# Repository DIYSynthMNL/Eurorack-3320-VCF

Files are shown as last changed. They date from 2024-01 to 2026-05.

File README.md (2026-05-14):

# Eurorack-3320-VCF

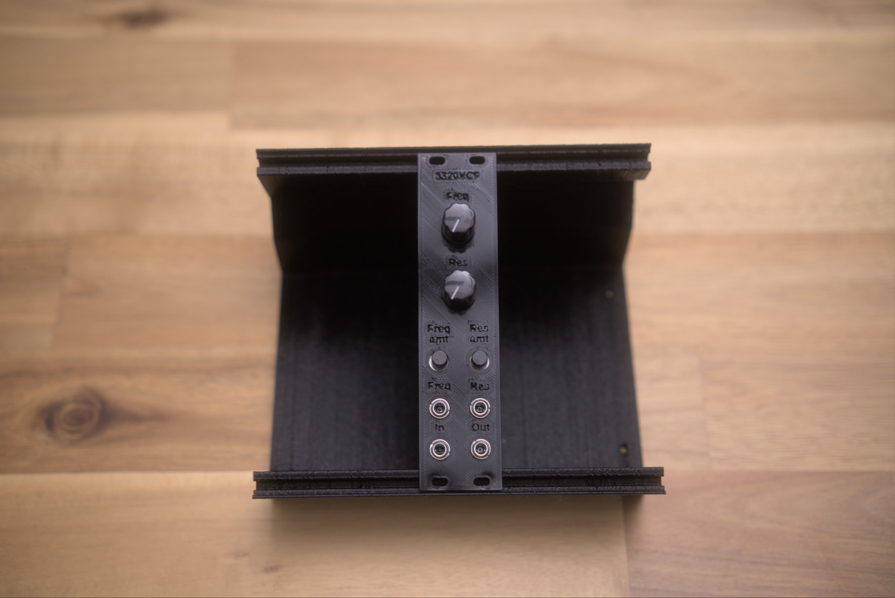
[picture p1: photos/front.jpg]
AS3320 VCF assembled


A Eurorack 4-pole low-pass voltage-controlled filter based on the [AS3320](https://electricdruid.net/product/as3320-vcf/) chip from Electric Druid — a high-performance 4-pole VCF (CEM3372 family). 12-octave cutoff sweep range and voltage-controlled resonance from zero to oscillation.

## Features

- **4-pole (24 dB/oct) low-pass response** using all four AS3320 filter stages
- **12-octave cutoff range** with smooth exponential control
- **Voltage-controlled resonance** — from zero to self-oscillation
- **Cutoff frequency** controlled by a panel pot + CV input with attenuation
- **Resonance** controlled by a panel pot + CV input with attenuation
- **Three calibration trims**:
  - Freq CV gain trim (RV2)
  - Reso CV gain trim (RV5)
  - Output amplitude trim (RV1)
- Eurorack ±12V power via either 16-pin IDC or 3-pin JST connector
- "Sequential Pro One"-style output buffer with AC coupling
- Audio inputs handle 10 Vpp directly (no input AC coupling needed)

## Inputs and outputs

| Jack | Range | Notes |
|---|---|---|
| Sig In | 10 Vpp | Through 100K input buffer, then to filter chain via 91K |
| Freq CV | 10 Vpp | Mixed with front-panel Freq Control via summing amp |
| Res CV | 10 Vpp | Mixed with front-panel Reso Control via summing amp |
| Sig Out | ≤9 Vpp | AC-coupled, gain-2 output buffer with amplitude trim |

## Block diagram

```
Sig In ─► [TL072 input buffer, U1A] ─► [91K] ─► AS3320 IN1
                                                  │
                                                  ▼ Stage 1 (LP)
                                                IN2 ─► Stage 2 (LP) ─► IN3 ─► Stage 3 (LP) ─► IN4 ─► Stage 4 (LP) ─► Out4
                                                                                                                       │
                                                                                                                       ▼
                                                                                                              [2.2 µF AC couple]
                                                                                                                       │
                                                                                                                       ▼
                                                                                                       [TL072 gain-2 + amp trim] ─► Sig Out
                                                                                                                       │
                                                                                                                       └─► [3.3K] ─► AS3320 Vres (resonance feedback)

Freq Control pot ─► [100K] ─┬─► [TL074 summing amp + RV2 gain trim] ─► AS3320 VCFI (pin 12)
Freq CV jack (RV4 atten) ──►┘

Reso Control pot ─► [100K] ─┬─► [TL074 stage 1 + RV5 gain trim] ─► [TL074 stage 2, 100K/150K] ─► [3.3K] ─► AS3320 Ires (pin 9)
Reso CV jack (RV7 atten) ──►┘

Power: Eurorack ±12V ─► local +12V (filtered) and −12V (filtered)
       AS3320 VEE: −12V via REE (R22 = 1.2K) → internal −2.7V regulator
       AS3320 VCC: +12V direct
       Filter stage Rb resistors (R12/R13/R14): 220K to −12V (note: 240K recommended for +12V VCC per datasheet)
       Filter timing caps (C3–C6): 270 pF each (cap1–cap4 pins)
```

## Power

- Eurorack ±12V via **J5** (3-pin JST) or **J6** (16-pin IDC) — populate one
- D1 / D2: reverse-polarity protection
- C9 / C12 (22 µF): bulk rail decoupling
- C10 / C11 (100 nF): op-amp supply decoupling
- **R22 = 1.2 kΩ — AS3320 VEE current limit resistor.** *Required* — the chip has an internal −2.7V regulator and must not see more than ~8 mA on the VEE pin.

REE formula from datasheet: **REE = (|VEE| − 2.7) / 0.008**

| VEE supply | REE |
|---|---|
| −10V | 910 Ω |
| −12V | 1.2 kΩ ← *used here* |
| −15V | 1.5 kΩ |

## Calibration

Three trim pots. Adjust in order, with the module warmed up ~5 minutes.

**RV1 — Output amplitude trim.** Sets final output level. The chip's max output is roughly VCC − 3V (so ~9 Vpp at +12V). Trim until output reaches 10 Vpp at modest input + maximum resonance.

**RV2 — Freq CV gain trim.** Sets the gain of the Freq CV path. Tune to taste — full range of the Freq CV jack should produce a musically-useful filter sweep.

**RV5 — Reso CV gain trim.** Sets the gain of the Reso CV path. At maximum reso CV, filter should reach self-oscillation; at minimum, no resonance.

Procedure:
1. With the module warmed up, set Freq Control to mid, Reso Control to min, no inputs patched.
2. Patch a steady audio signal (sawtooth from a VCO, ~−10 dB) into Sig In and a scope on Sig Out.
3. Adjust RV1 until peak output is ~10 Vpp without clipping.
4. Sweep Freq Control by hand; should hear the filter open and close smoothly.
5. Raise Reso Control — should hear the resonant peak grow, eventually self-oscillating at high values.
6. With a 0–5V LFO patched into Reso CV (jack pot RV7 fully open), adjust RV5 to get the same self-oscillation behavior when CV-driven as you got from the panel pot.
7. With a 0–5V LFO patched into Freq CV (jack pot RV4 fully open), adjust RV2 to get a similar full-range sweep when CV-driven.

## Design references

Local archived copies live in [`references/`](references/) so this repo stays useful if the upstream links die.

- **AS3320 datasheet** — [local copy](references/AS3320-alfatriode-2023.pdf) · [upstream (alfatriode.lv)](https://alfatriode.lv/eng/sc/AS3320.pdf) — definitive reference for the chip
- [Electric Druid AS3320 product page](https://electricdruid.net/product/as3320-vcf/)
- [Electric Druid multimode filter notes](https://electricdruid.net/multimode-filters-part-1-reconfigurable-filters/) — the AS3320 can be wired for LPF / HPF / BPF / APF; this design is LPF only
- Output buffer topology adapted from the Sequential Pro One synth
- [Falstad simulations](falstad/) of input, frequency control, resonance control, and output sub-circuits

## Build status

What's ready for builders today, and what's still on the TODO list:

**Production assets**

- [x] Schematic — Rev 0.1.5 ([PDF](Schematic%20PDFs/3320-VCF_Schematic-Rev-0.1.5.pdf))
- [ ] PCB layout — rev 0.1.0 separated for fab in `kicad/Separate boards/rev0.1.0/`; schematic has advanced to 0.1.5, **re-separation pending**
- [ ] Gerber files for fabrication — none yet
- [ ] BOM — none yet
- [ ] Final front panel (SVG/PDF for fab) — none yet
- [ ] License — none yet

**Prototype assets**

- [x] 3D-printed prototype panel STL — [3320_VCF.stl](3D%20Printed%20Panel/3320_VCF.stl)
- [x] Falstad simulations — [falstad/](falstad/)

**Documentation**

- [x] Photos of the assembled module — see [photos/](photos/)
- [ ] Demo video — none yet
- [ ] Build / assembly instructions — none yet
- [x] Calibration / tuning notes — see "Calibration" section above

Want to help fill a gap (build photos, gerbers, an assembly guide)? Open an issue or PR.

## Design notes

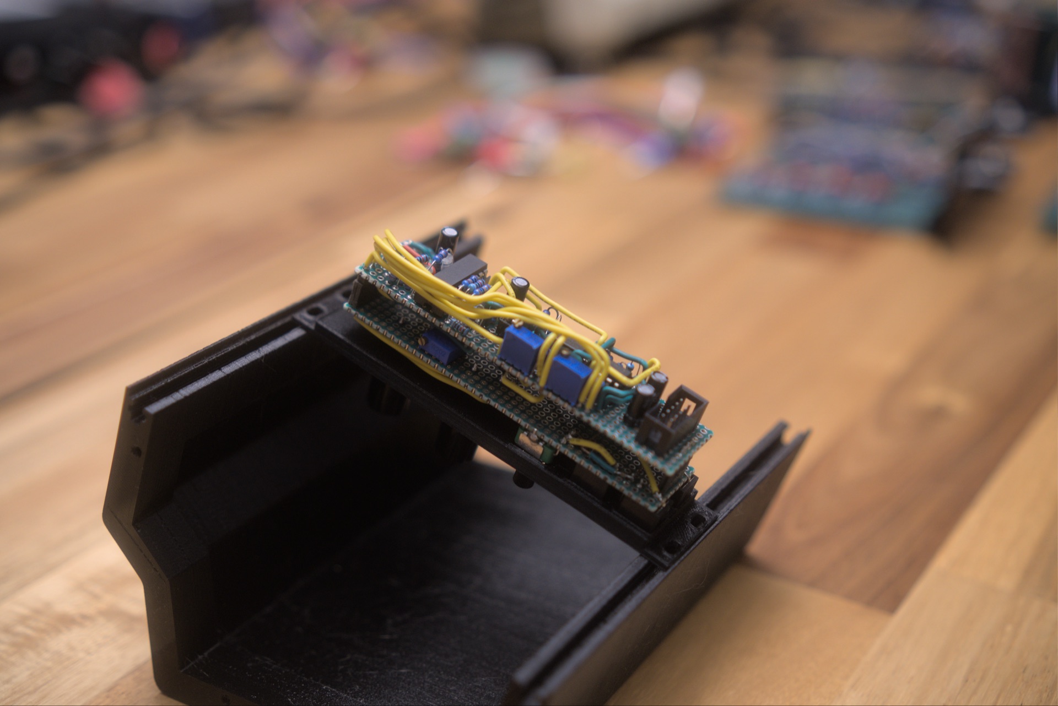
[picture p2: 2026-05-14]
photos/prototype-board-side.jpg

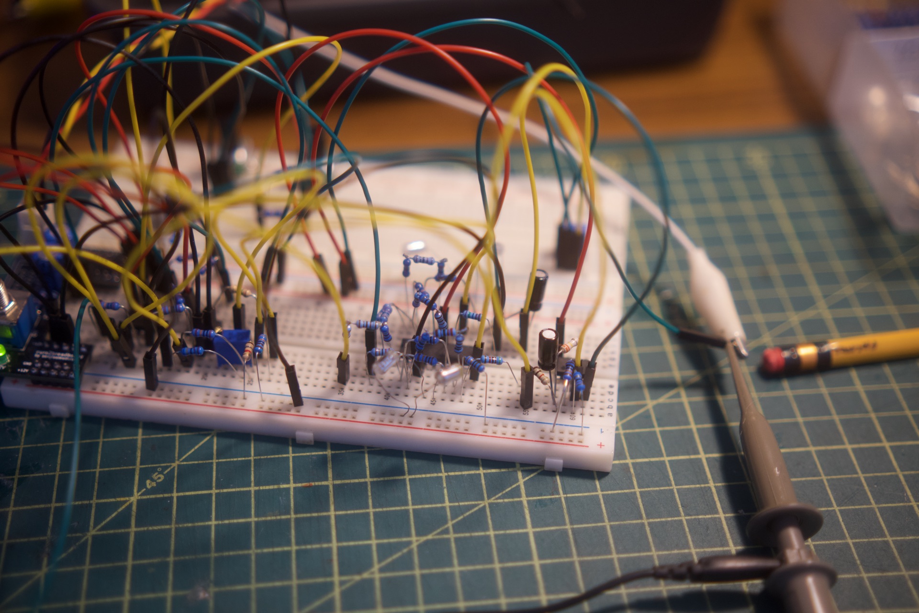
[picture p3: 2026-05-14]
photos/breadboarding/breadboard-2.jpg

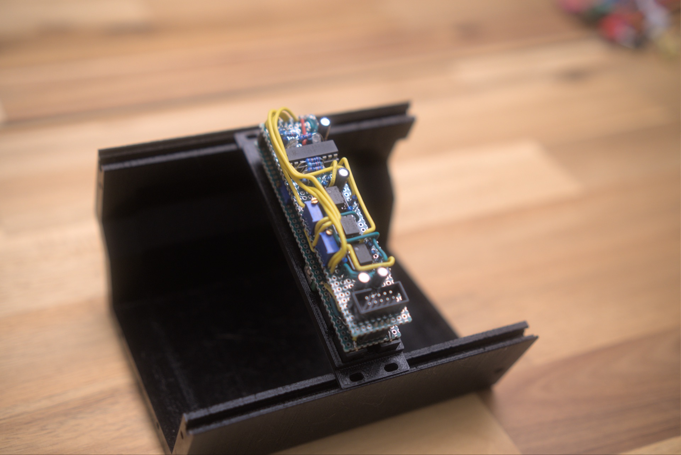
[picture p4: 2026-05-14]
photos/prototype-board.jpg

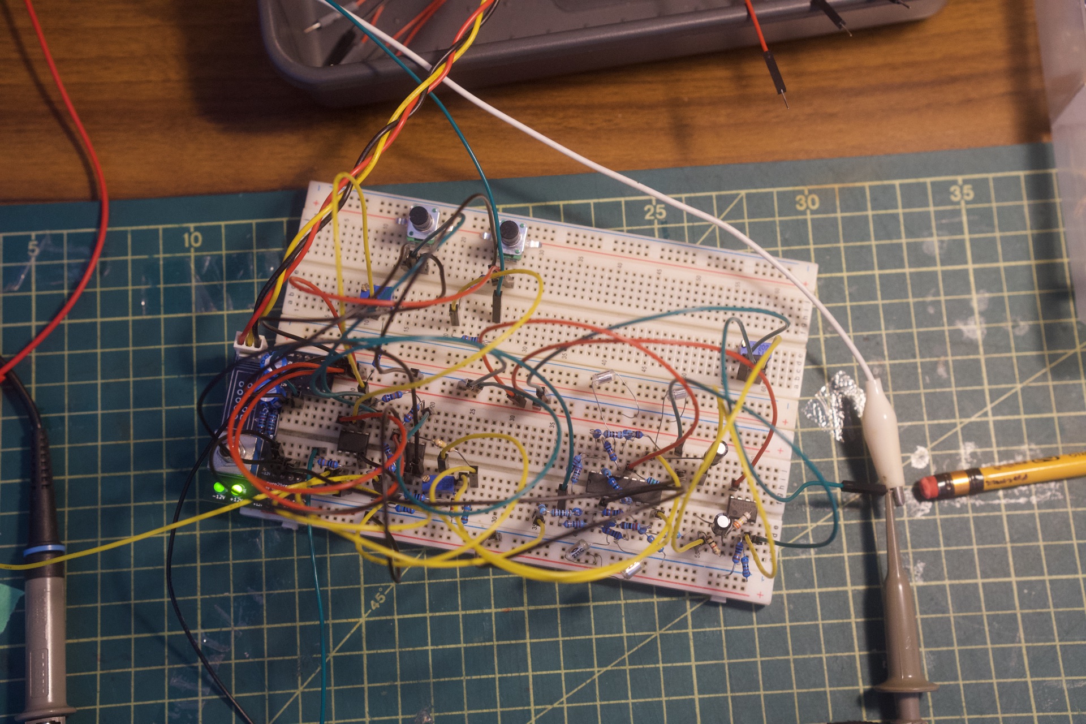
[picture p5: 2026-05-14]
photos/breadboarding/breadboard-1.jpg

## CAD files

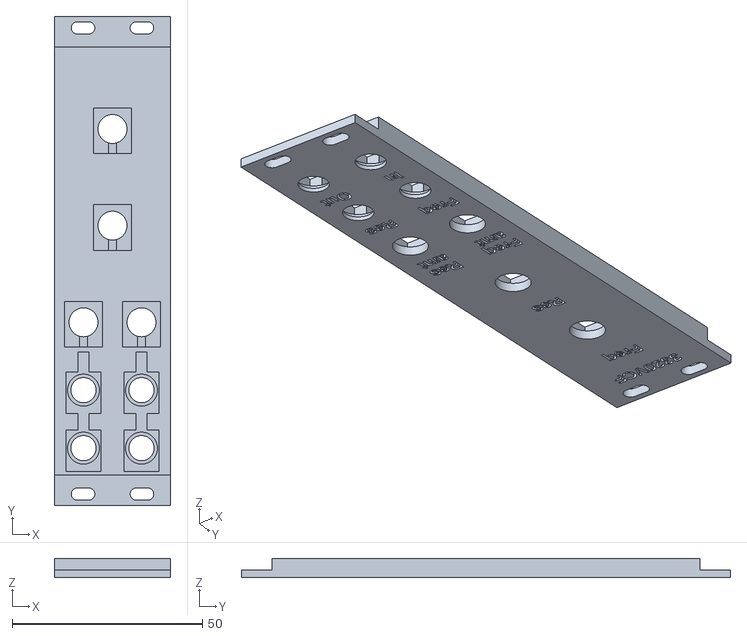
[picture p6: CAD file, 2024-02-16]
3D Printed Panel/3320_VCF.stl
30.5 x 128.5 x 5.00

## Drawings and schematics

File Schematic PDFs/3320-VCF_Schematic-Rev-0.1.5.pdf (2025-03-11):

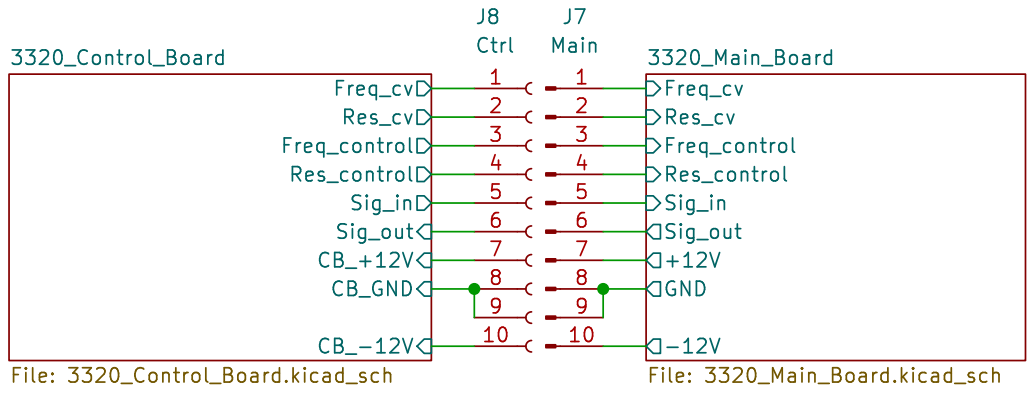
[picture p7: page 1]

File: 3320-VCF.kicad_sch Sheet: / DIYSynthMNL

Id: 1/3 Title: Eurorack 3320 Low Pass VCF

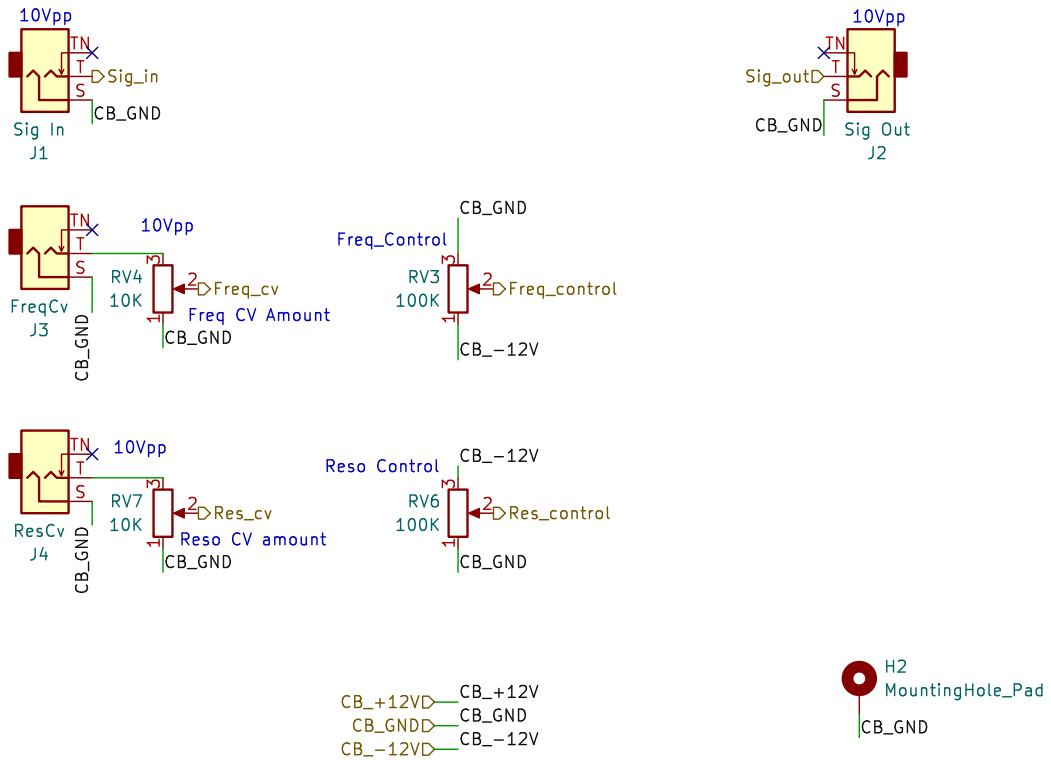
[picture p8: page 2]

DIYSynthMNL
File: 3320_Control_Board.kicad_sch Sheet: /3320_Control_Board/
Id: 2/3 Title: Eurorack 3320 Low Pass VCF

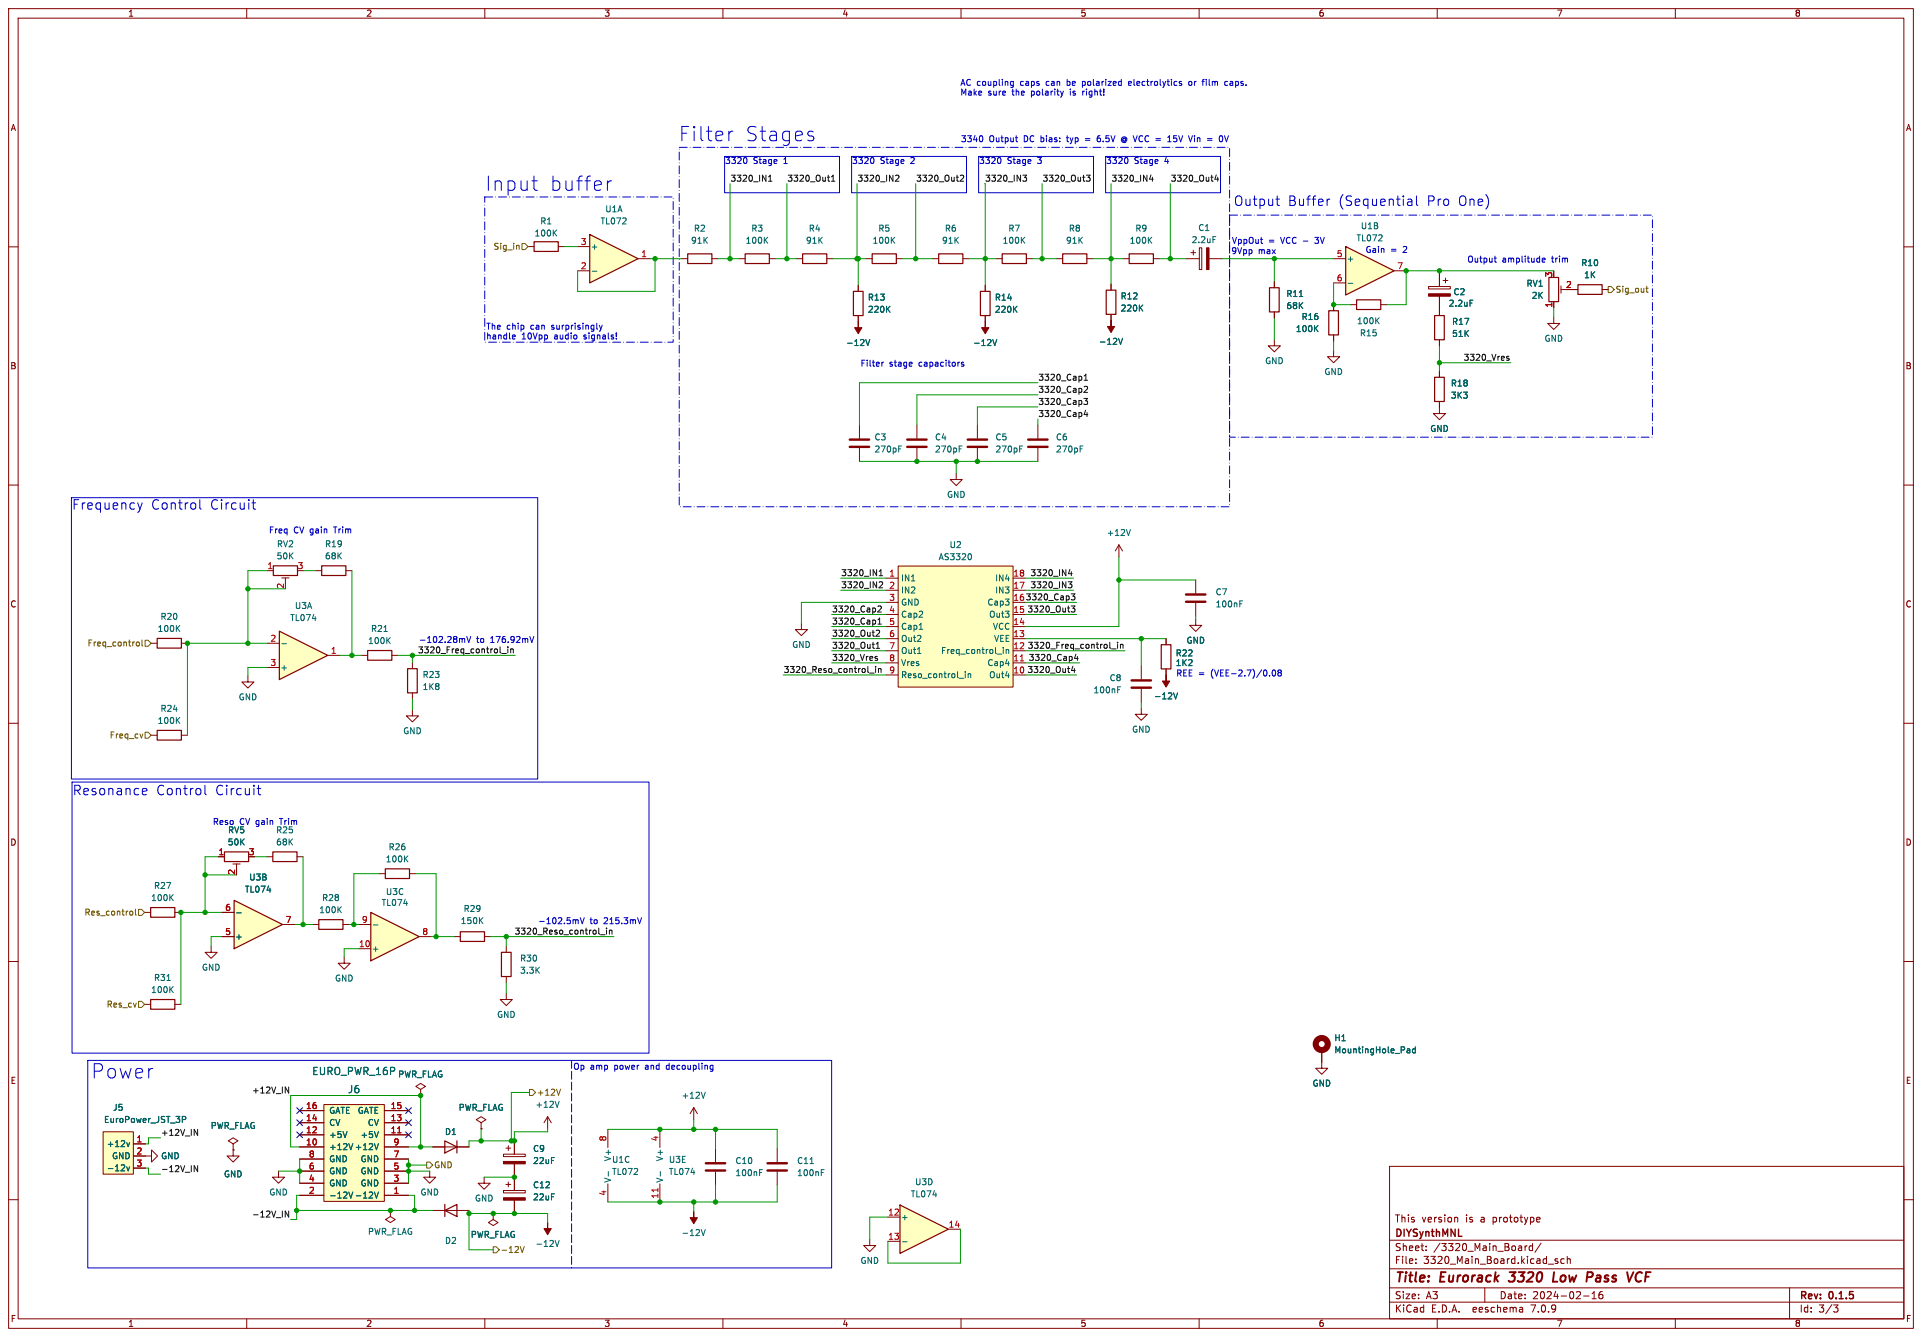
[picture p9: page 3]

3320 Stage 4 Freq CV gain Trim

VppOut = VCC - 3V Resonance Control Circuit

9Vpp max Reso CV gain Trim

The chip can surprisingly handle 10Vpp audio signals!

Op amp power and decoupling

DIYSynthMNL
File: 3320_Main_Board.kicad_sch Sheet: /3320_Main_Board/
Id: 3/3 Title: Eurorack 3320 Low Pass VCF

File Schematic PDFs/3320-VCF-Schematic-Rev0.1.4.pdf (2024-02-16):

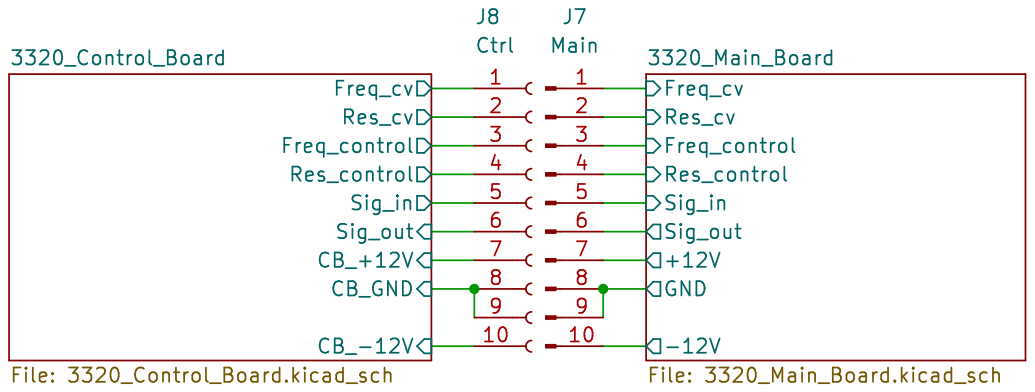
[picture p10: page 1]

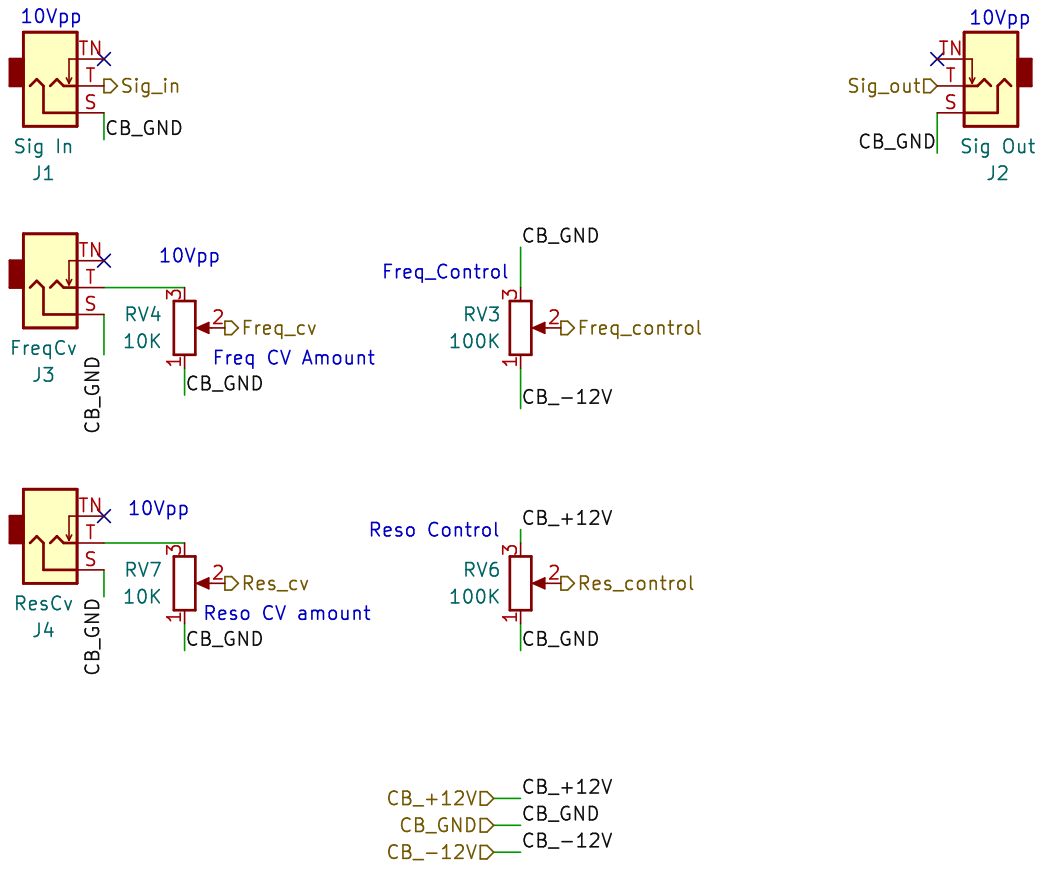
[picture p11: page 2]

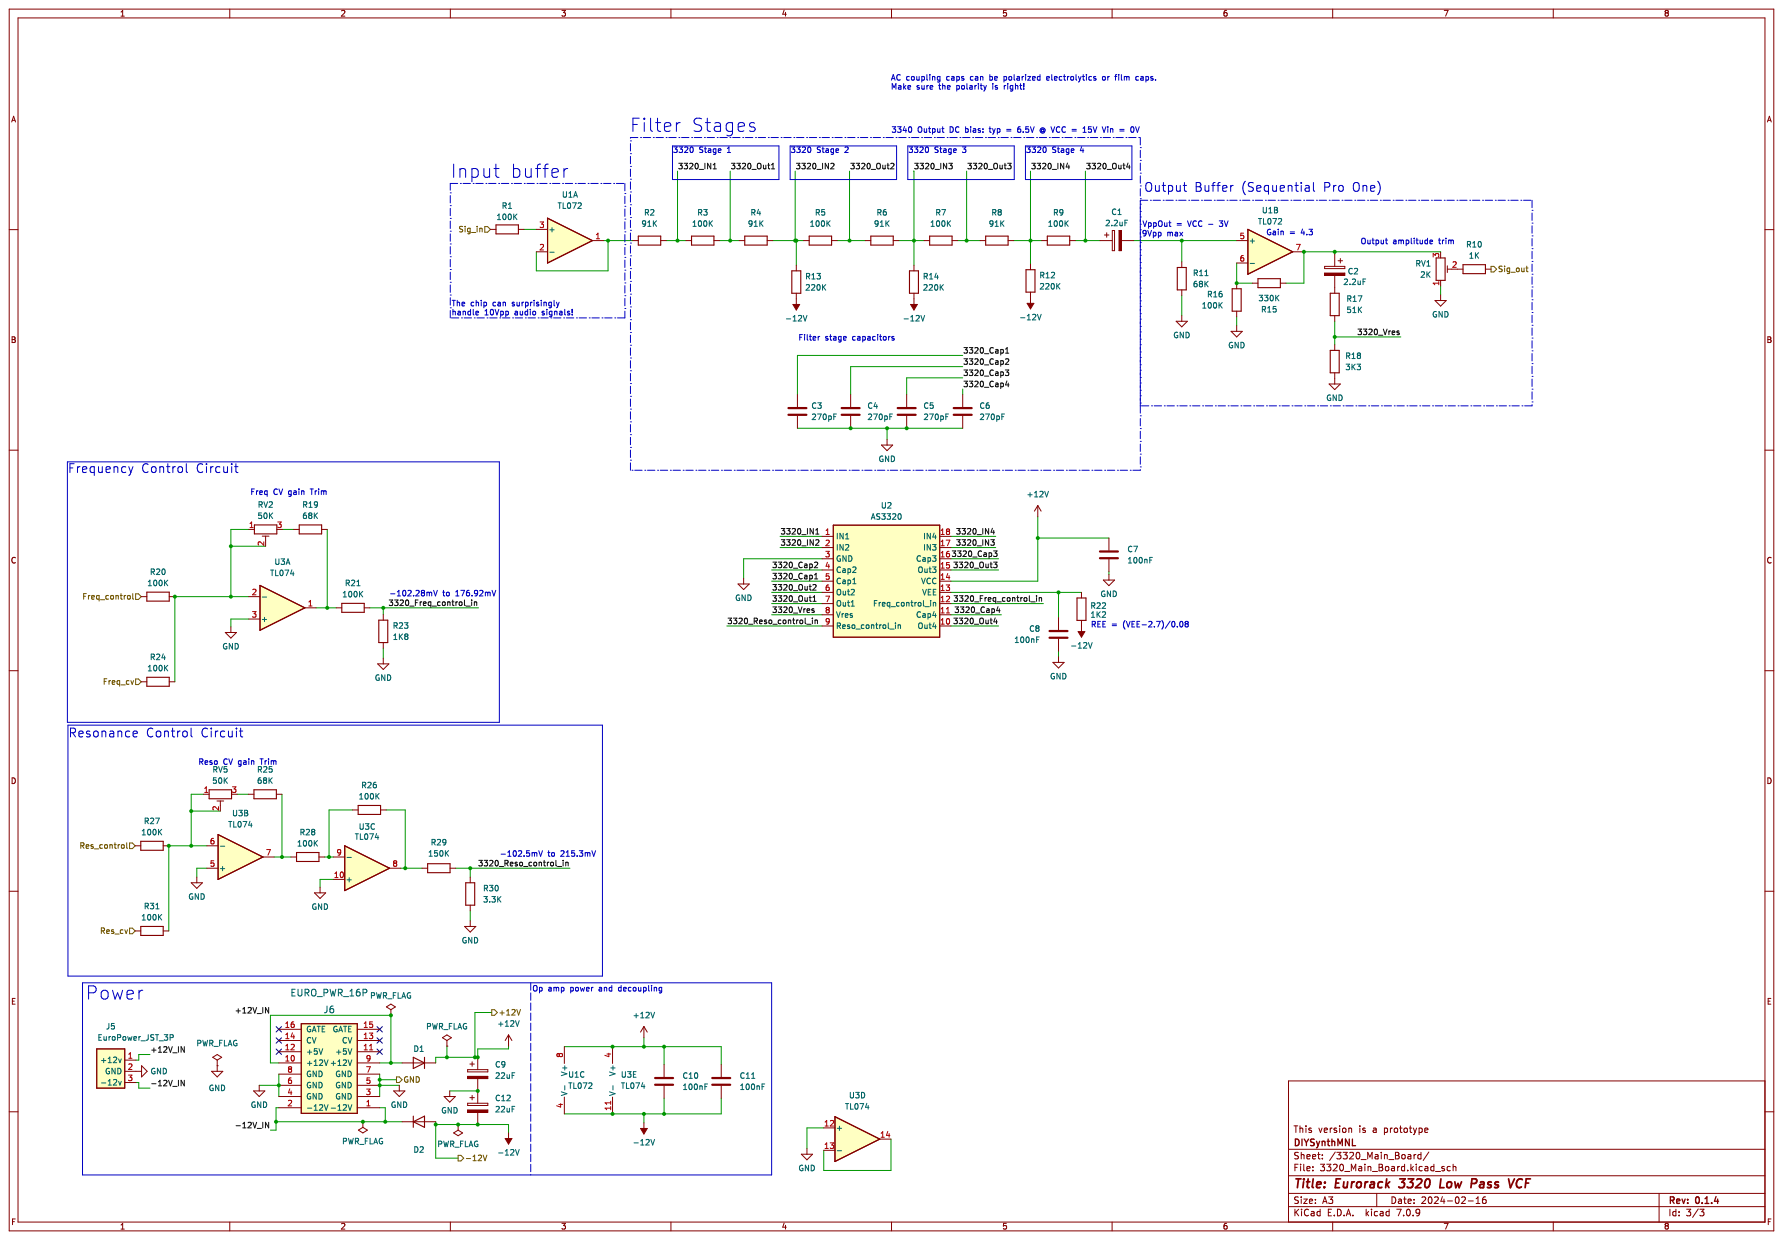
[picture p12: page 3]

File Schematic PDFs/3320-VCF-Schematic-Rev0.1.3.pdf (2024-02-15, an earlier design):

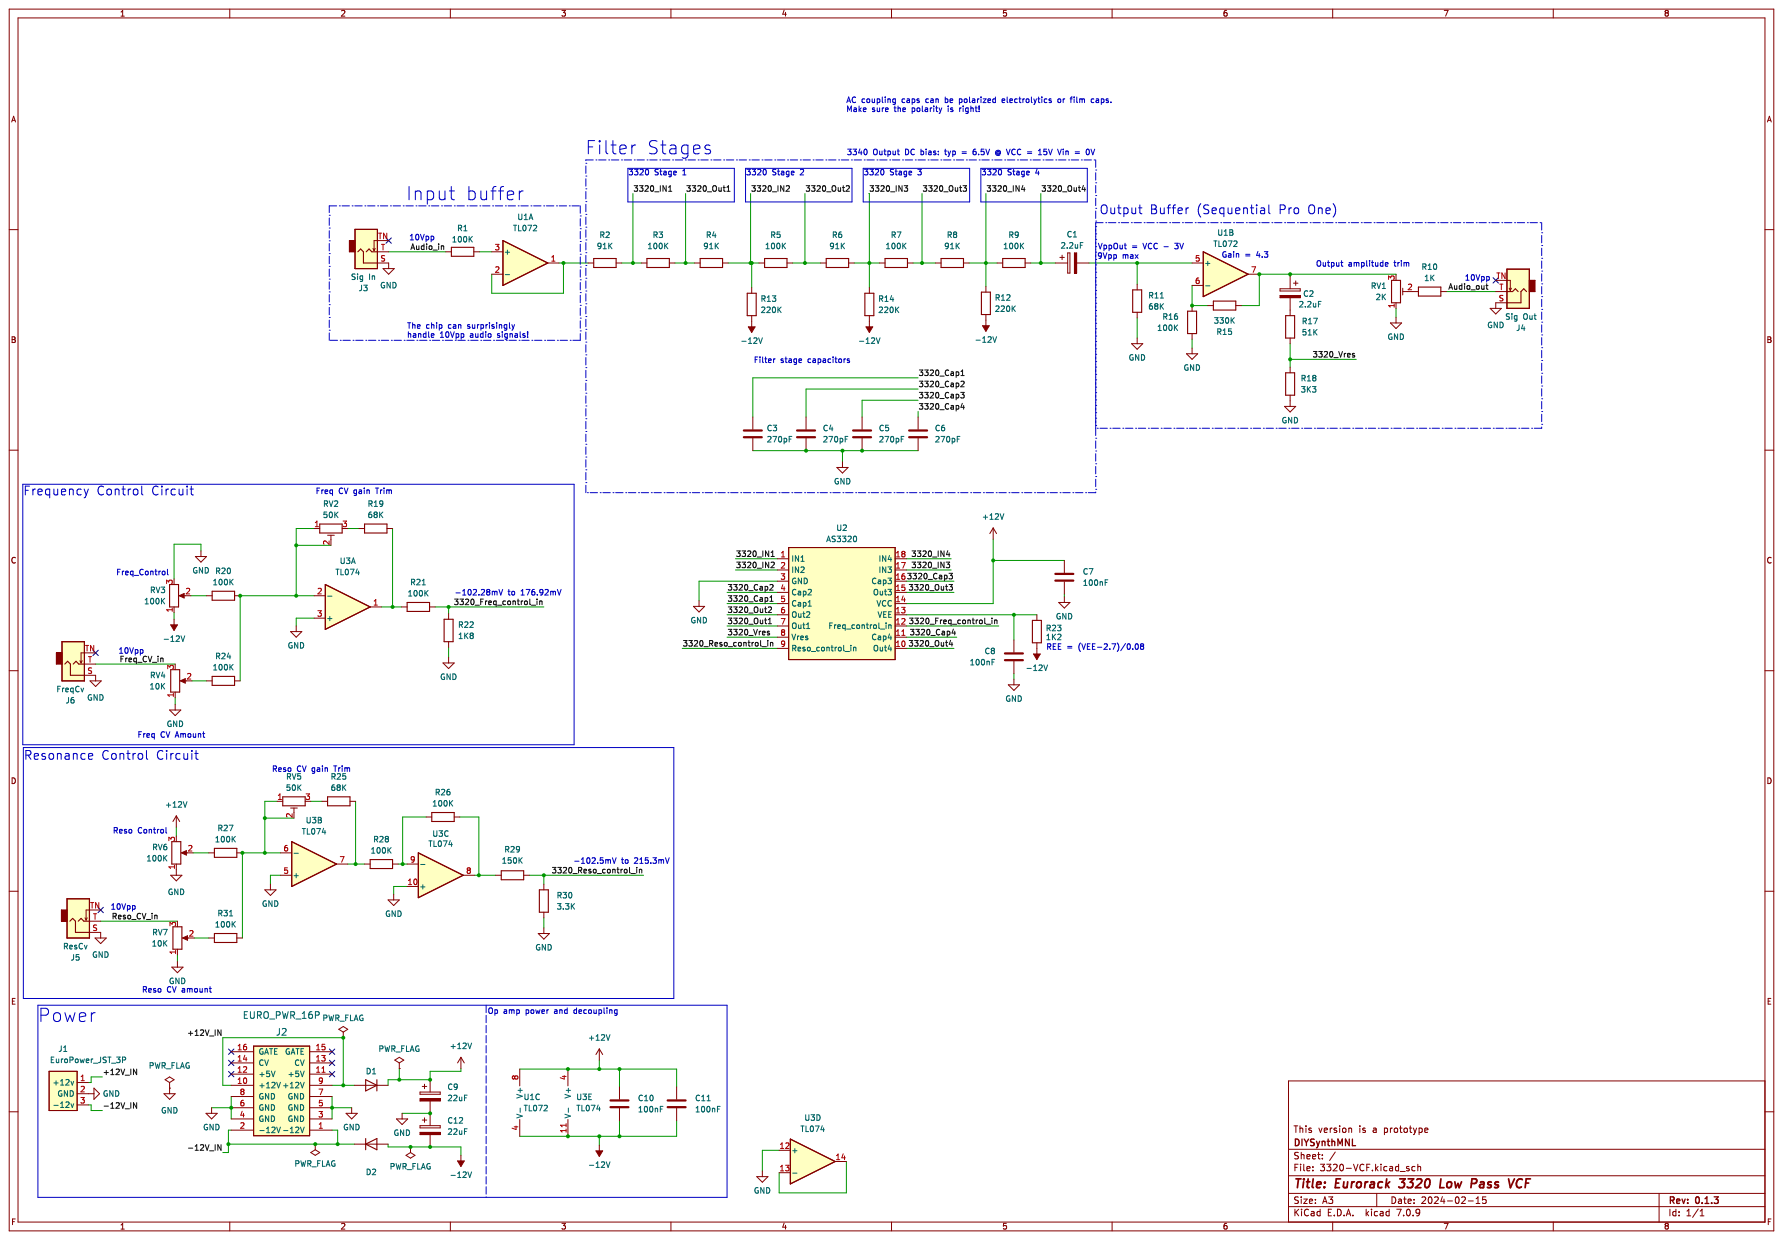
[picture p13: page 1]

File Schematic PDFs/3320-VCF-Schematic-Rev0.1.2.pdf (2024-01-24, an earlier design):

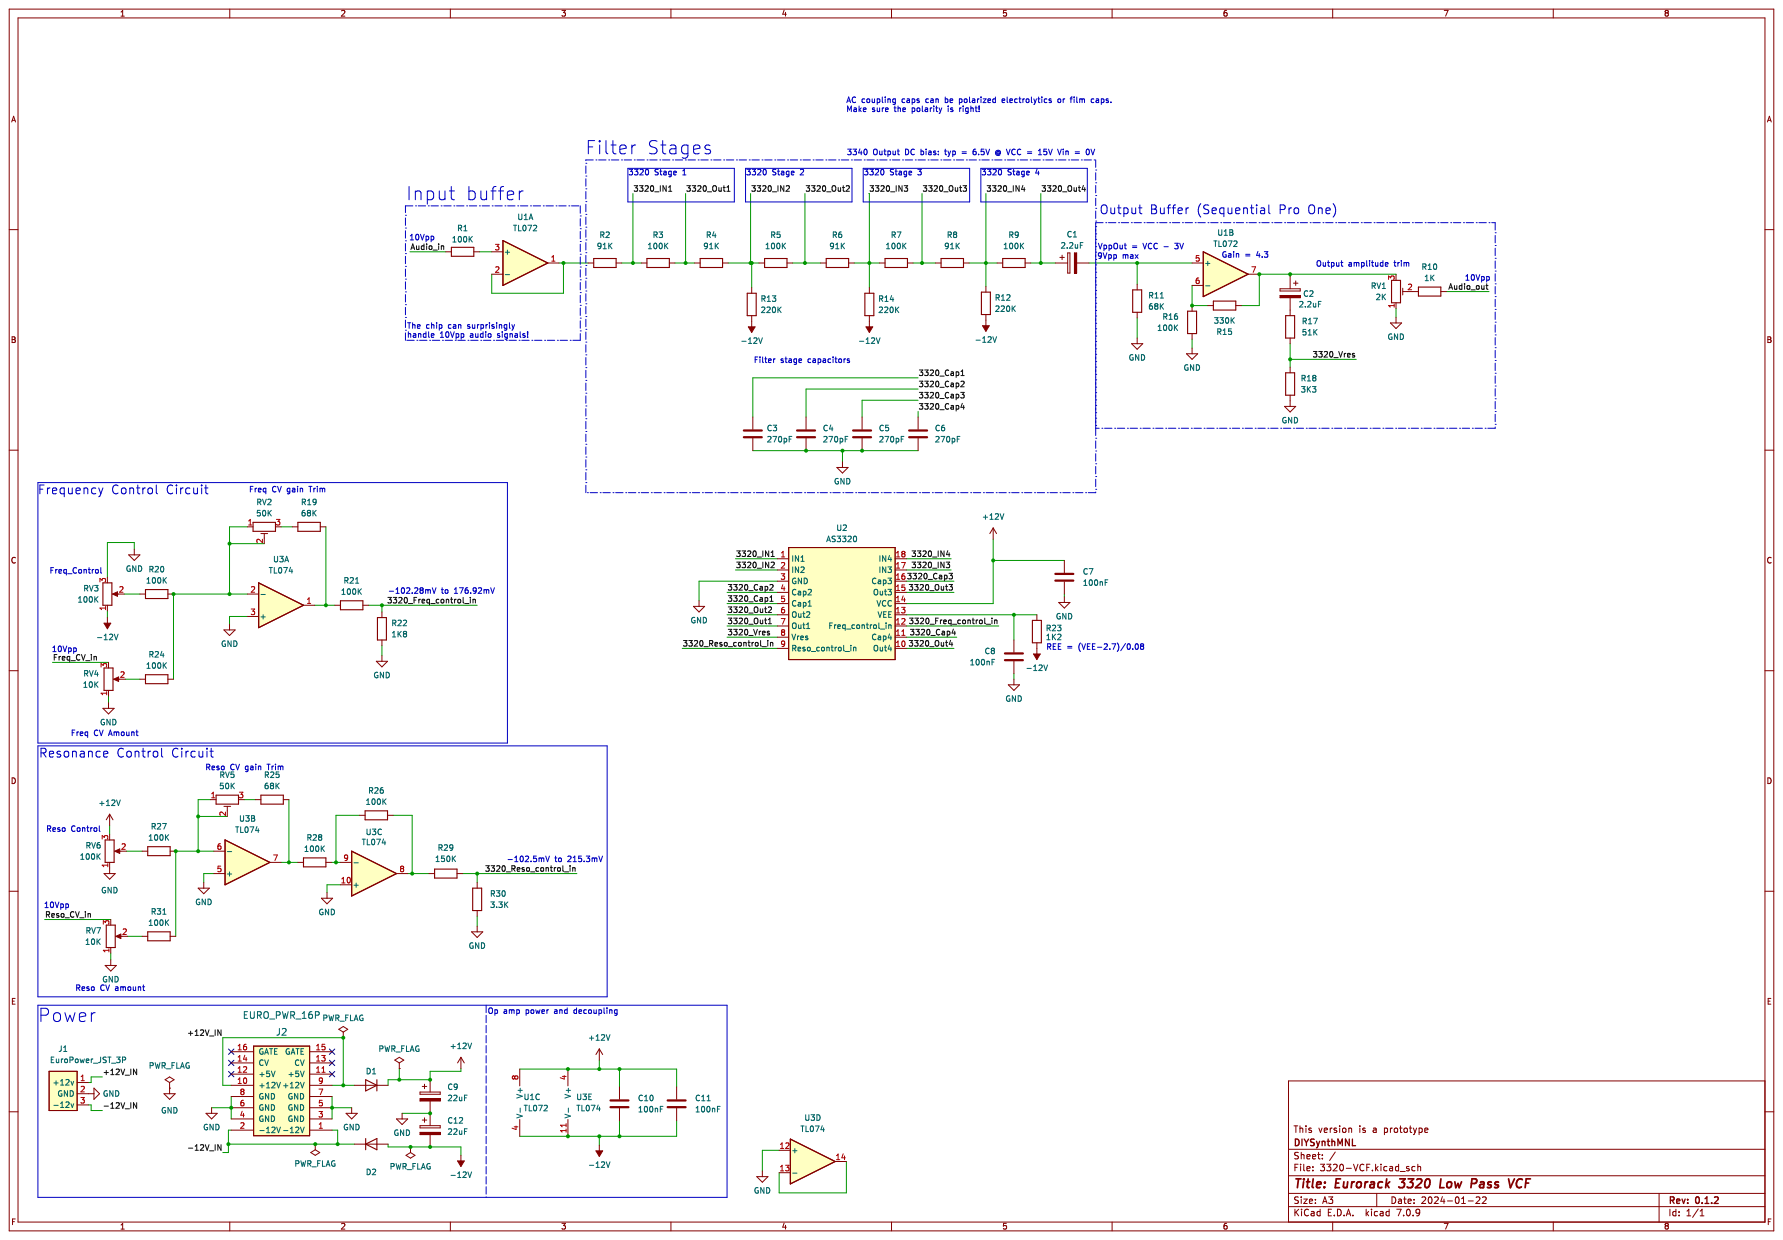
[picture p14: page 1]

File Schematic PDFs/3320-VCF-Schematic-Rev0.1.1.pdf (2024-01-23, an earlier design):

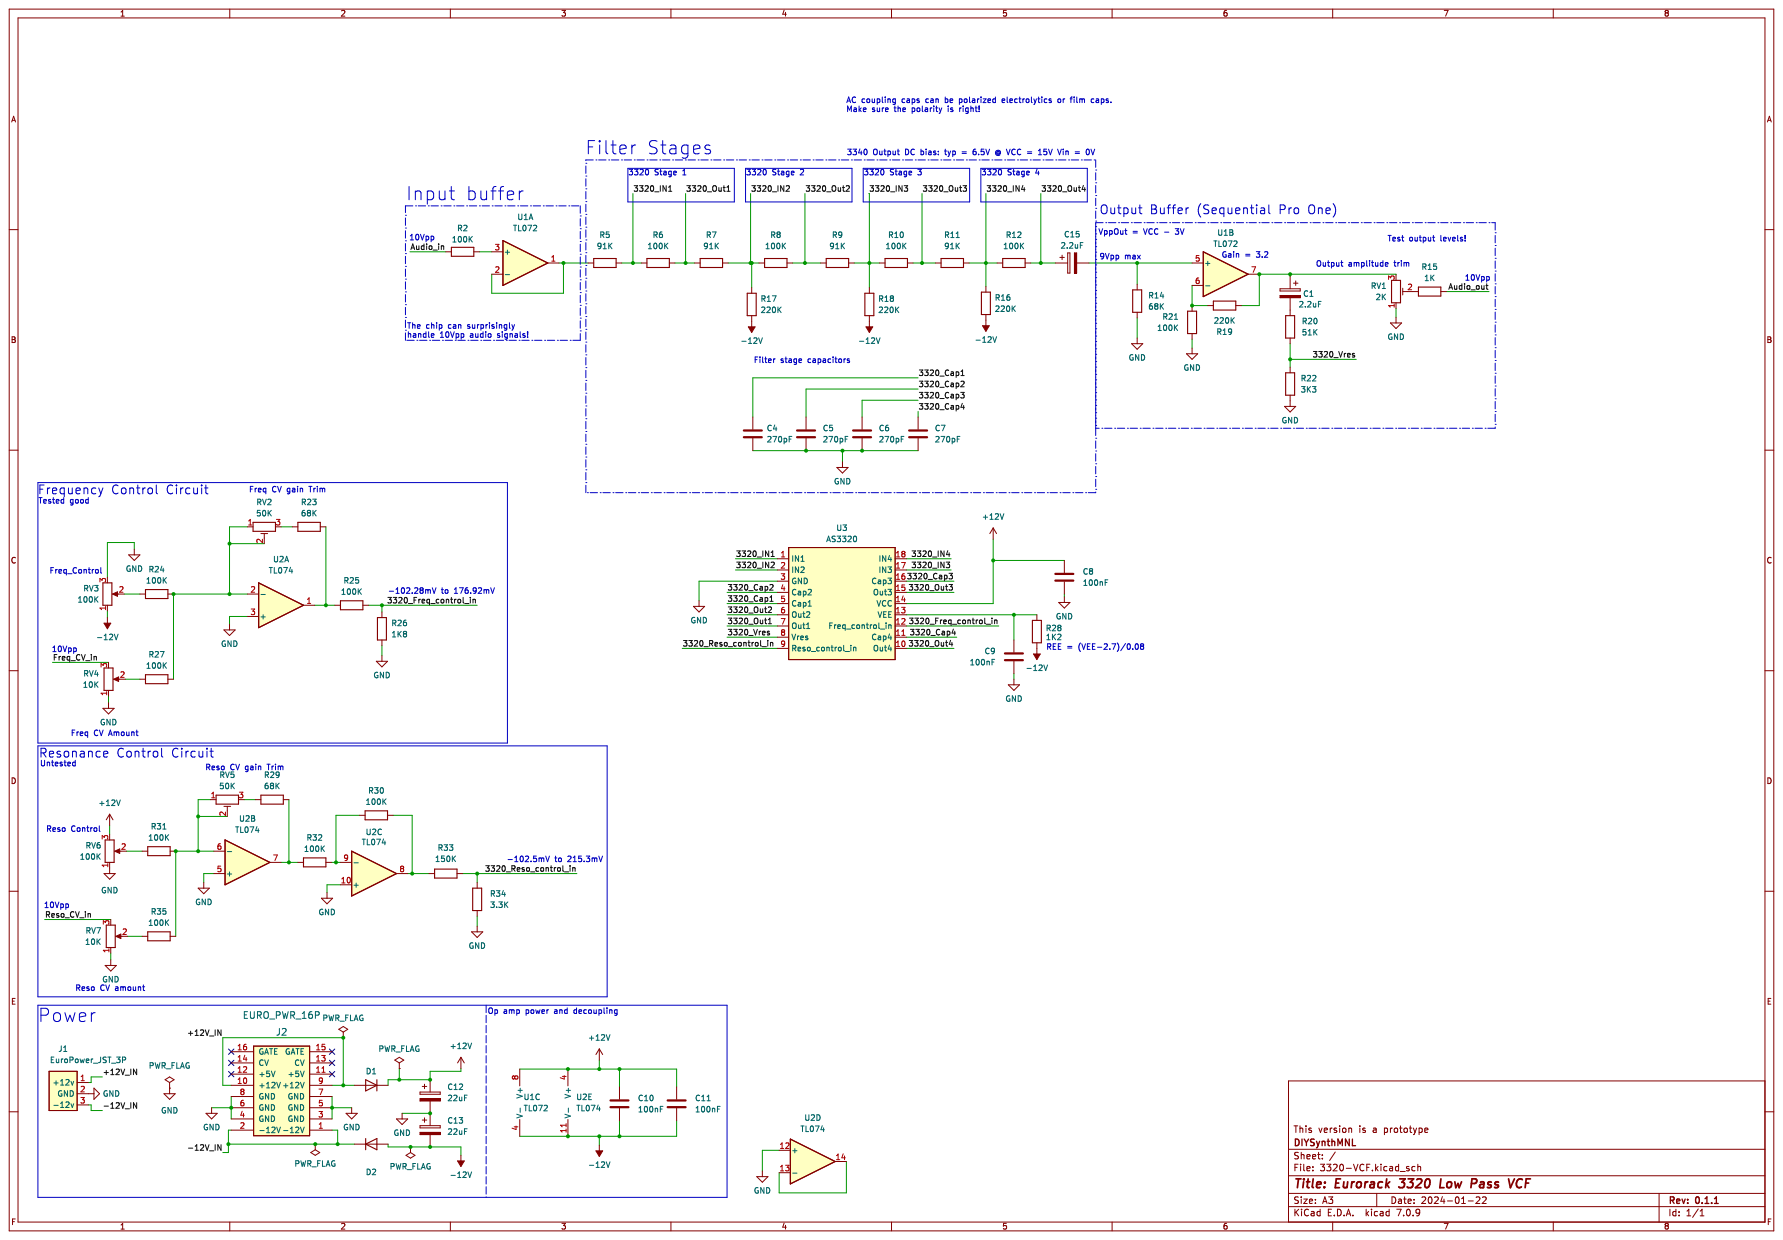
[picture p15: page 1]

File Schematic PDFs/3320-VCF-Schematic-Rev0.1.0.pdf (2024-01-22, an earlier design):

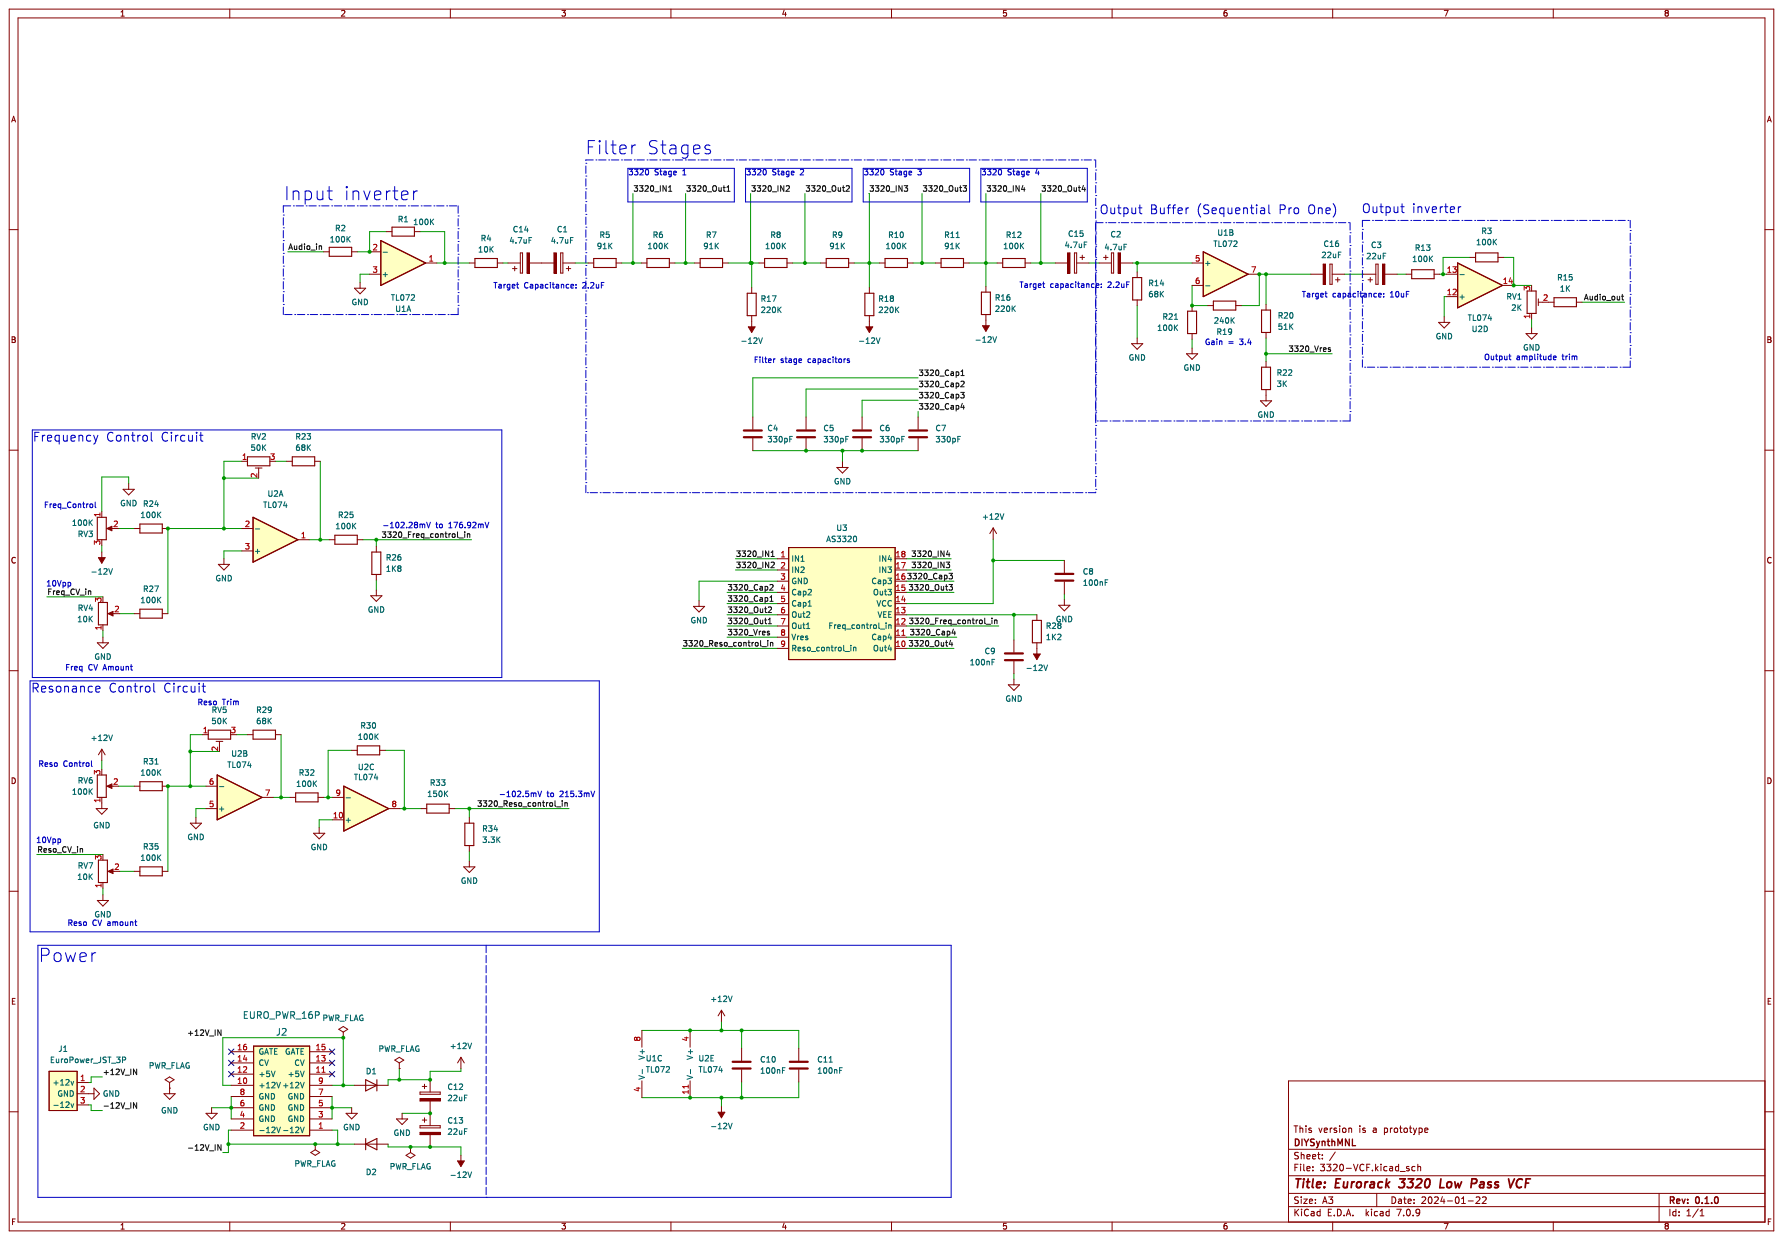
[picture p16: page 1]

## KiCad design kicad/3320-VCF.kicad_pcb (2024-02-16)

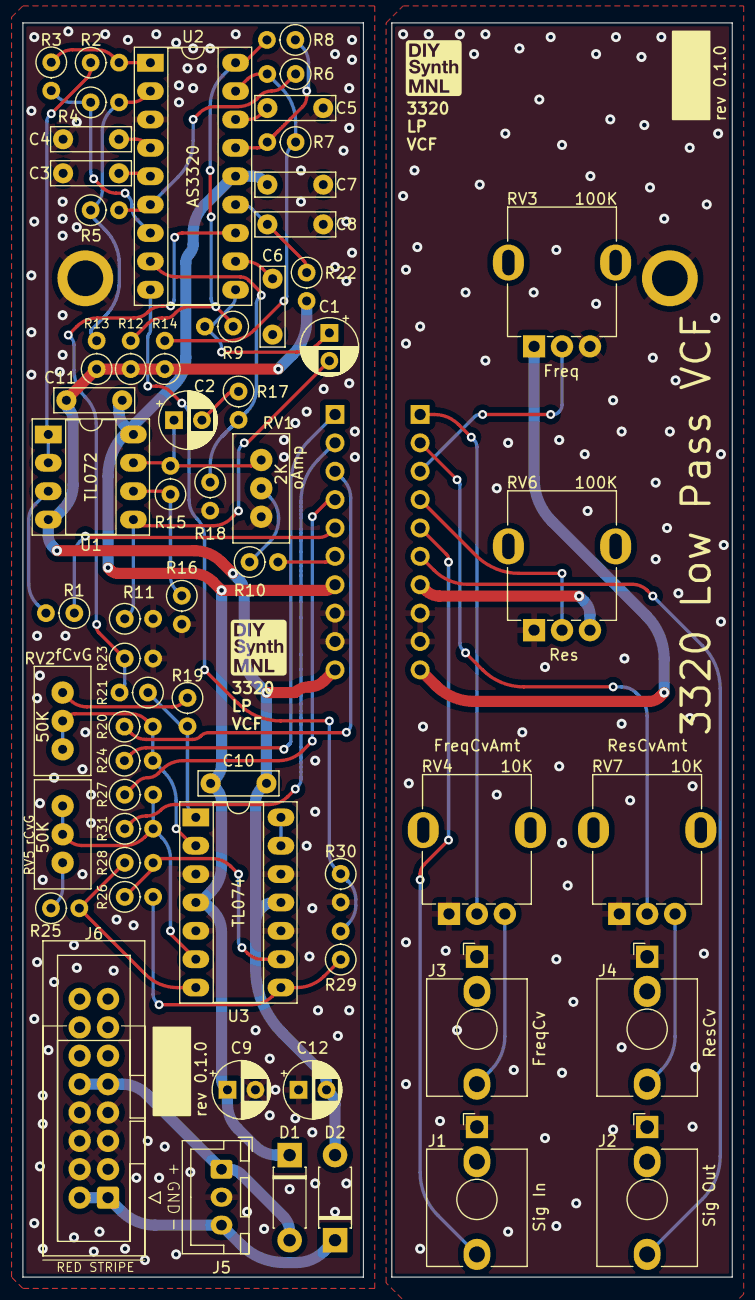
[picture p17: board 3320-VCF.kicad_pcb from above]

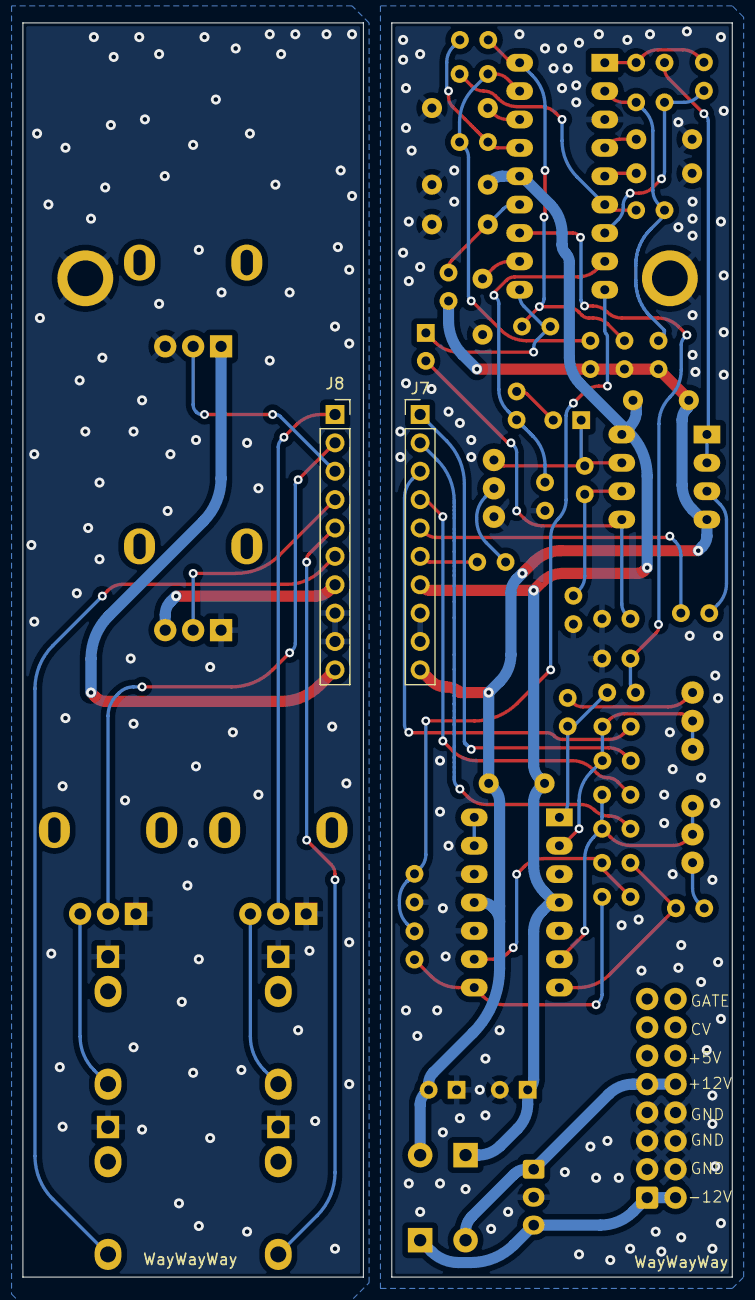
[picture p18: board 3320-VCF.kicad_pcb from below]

Board: 2 copper layers, 63.5 x 112.3 mm, 67 parts (2 on the bottom side), 54 nets.

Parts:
A: Board
B: Board
C1, C2: 2.2uF; CP_Radial_D5.0mm_P2.50mm
C3, C4, C5, C6: 270pF; C_Rect_L7.0mm_W2.0mm_P5.00mm_BigPads
C7, C8, C10, C11: 100nF; C_Rect_L7.0mm_W2.0mm_P5.00mm_BigPads
C9, C12: 22uF; CP_Radial_D5.0mm_P2.50mm
D1, D2: D_DO-41_SOD81_P7.62mm_Horizontal_BigPads
H1, H2: MountingHole_Pad; MountingHole_M3_Standoff_Pad
J1: Sig In; AudioJack_3.5mm_long_pads
J2: Sig Out; AudioJack_3.5mm_long_pads
J3: FreqCv; AudioJack_3.5mm_long_pads
J4: ResCv; AudioJack_3.5mm_long_pads
J5: EuroPower_JST_3P; Eurorack_power_jst_3P
J6: EURO_PWR_16P; IDC-Header_2x08_P2.54mm_Vertical
J7: Main; PinHeader_1x10_P2.54mm_Vertical
J8: Ctrl; PinSocket_1x10_P2.54mm_Vertical
R1, R3, R5, R7, R9, R16, R20, R21, R24, R26, R27, R28, R31: 100K; R_Axial_DIN0207_L6.3mm_D2.5mm_P2.54mm_Vertical
R2, R4, R6, R8: 91K; R_Axial_DIN0207_L6.3mm_D2.5mm_P2.54mm_Vertical
R10: 1K; R_Axial_DIN0207_L6.3mm_D2.5mm_P2.54mm_Vertical
R11, R19, R25: 68K; R_Axial_DIN0207_L6.3mm_D2.5mm_P2.54mm_Vertical
R12, R13, R14: 220K; R_Axial_DIN0207_L6.3mm_D2.5mm_P2.54mm_Vertical
R15: 330K; R_Axial_DIN0207_L6.3mm_D2.5mm_P2.54mm_Vertical
R17: 51K; R_Axial_DIN0207_L6.3mm_D2.5mm_P2.54mm_Vertical
R18: 3K3; R_Axial_DIN0207_L6.3mm_D2.5mm_P2.54mm_Vertical
R22: 1K2; R_Axial_DIN0207_L6.3mm_D2.5mm_P2.54mm_Vertical
R23: 1K8; R_Axial_DIN0207_L6.3mm_D2.5mm_P2.54mm_Vertical
R29: 150K; R_Axial_DIN0207_L6.3mm_D2.5mm_P2.54mm_Vertical
R30: 3.3K; R_Axial_DIN0207_L6.3mm_D2.5mm_P2.54mm_Vertical
RV1: 2K; Potentiometer_Bourns_3296W_Vertical_BigPads
RV2, RV5: 50K; Potentiometer_Bourns_3296W_Vertical_BigPads
RV3, RV6: 100K; Potentiometer_RV09_BigPads
RV4, RV7: 10K; Potentiometer_RV09_BigPads
U1: TL072; DIP-8_W7.62mm_Socket_LongPads
U2: AS3320; DIP-18_W7.62mm_Socket_LongPads
U3: TL074; DIP-14_W7.62mm_Socket_LongPads

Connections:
+12V: C7.1, C9.1, C10.1, C11.1, D1.1 (K), J7.7, U1.8 (V+), U2.14 (VCC), U3.4 (V+)
-12V: C10.2, C11.2, C12.2, D2.2 (A), J7.10, R12.1, R13.1, R14.1, R22.2, U1.4 (V-), U3.11 (V-)
/3320_Control_Board/CB_+12V: J8.7, RV6.3
/3320_Control_Board/CB_-12V: J8.10, RV3.1
/3320_Control_Board/CB_GND: H2.1, J1.S, J2.S, J3.S, J4.S, J8.8, J8.9, RV3.3, RV4.1, RV6.1, RV7.1
/3320_Control_Board/Freq_control: J8.3, RV3.2
/3320_Control_Board/Freq_cv: J8.1, RV4.2
/3320_Control_Board/Res_control: J8.4, RV6.2
/3320_Control_Board/Res_cv: J8.2, RV7.2
/3320_Control_Board/Sig_in: J1.T, J8.5
/3320_Control_Board/Sig_out: J2.T, J8.6
/3320_Main_Board/3320_Cap1: C3.1, U2.5 (Cap1)
/3320_Main_Board/3320_Cap2: C4.1, U2.4 (Cap2)
/3320_Main_Board/3320_Cap3: C5.1, U2.16 (Cap3)
/3320_Main_Board/3320_Cap4: C6.1, U2.11 (Cap4)
/3320_Main_Board/3320_Freq_control_in: R21.2, R23.1, U2.12 (Freq_control_in)
/3320_Main_Board/3320_IN1: R2.2, R3.1, U2.1 (IN1)
/3320_Main_Board/3320_IN2: R4.2, R5.1, R13.2, U2.2 (IN2)
/3320_Main_Board/3320_IN3: R6.2, R7.1, R14.2, U2.17 (IN3)
/3320_Main_Board/3320_IN4: R8.2, R9.1, R12.2, U2.18 (IN4)
/3320_Main_Board/3320_Out1: R3.2, R4.1, U2.7 (Out1)
/3320_Main_Board/3320_Out2: R5.2, R6.1, U2.6 (Out2)
/3320_Main_Board/3320_Out3: R7.2, R8.1, U2.15 (Out3)
/3320_Main_Board/3320_Out4: C1.1, R9.2, U2.10 (Out4)
/3320_Main_Board/3320_Reso_control_in: R29.2, R30.1, U2.9 (Reso_control_in)
/3320_Main_Board/3320_Vres: R17.2, R18.1, U2.8 (Vres)
/3320_Main_Board/+12V_IN: D1.2 (A), J5.1 (+12v), J6.9 (+12V), J6.10 (+12V)
/3320_Main_Board/-12V_IN: D2.1 (K), J5.3 (-12v), J6.1 (-12V), J6.2 (-12V)
/3320_Main_Board/Freq_control: J7.3, R20.1
/3320_Main_Board/Freq_cv: J7.1, R24.1
/3320_Main_Board/Res_control: J7.4, R27.1
/3320_Main_Board/Res_cv: J7.2, R31.1
/3320_Main_Board/Sig_in: J7.5, R1.1
/3320_Main_Board/Sig_out: J7.6, R10.2
GND: C3.2, C4.2, C5.2, C6.2, C7.2, C8.2, C9.2, C12.1, H1.1, J5.2 (GND), J6.3 (GND), J6.4 (GND), J6.5 (GND), J6.6 (GND), J6.7 (GND), J6.8 (GND), J7.8, J7.9, R11.2, R16.2, R18.2, R23.2, R30.2, RV1.1, U2.3 (GND), U3.3 (+), U3.5 (+), U3.10 (+), U3.12 (+)
unnamed: C2.1, R15.2, RV1.3, U1.7
unnamed: C2.2, R17.1
unnamed: J3.T, RV4.3
unnamed: J4.T, RV7.3
unnamed: R10.1, RV1.2
unnamed: R19.1, RV2.3
unnamed: R19.2, R21.1, U3.1
unnamed: R25.1, RV5.3
unnamed: R25.2, R28.1, U3.7
unnamed: R26.2, R29.1, U3.8
unnamed: R1.2, U1.3 (+)
unnamed: R2.1, U1.1, U1.2 (-)
unnamed: C1.2, R11.1, U1.5 (+)
unnamed: R15.1, R16.1, U1.6 (-)
unnamed: C8.1, R22.1, U2.13 (VEE)
unnamed: R20.2, R24.2, RV2.1, RV2.2, U3.2 (-)
unnamed: R27.2, R31.2, RV5.1, RV5.2, U3.6 (-)
unnamed: R26.1, R28.2, U3.9 (-)
unnamed: U3.13 (-), U3.14

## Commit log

2024-01-22 drawn schematic rev 0.1.0
    [3320-VCF.kicad_pcb, 3320-VCF.kicad_sch]
2024-01-22 schematic updated
    [3320-VCF.kicad_sch]
2024-01-23 Added Schematic Revision 0.1.1
    [3320-VCF.kicad_sch]
2024-01-23 added Schematic rev 0.1.1 pdf
    [3320-VCF.kicad_sch]
2024-01-24 added schematic revision 0.1.2
    [3320-VCF.kicad_sch]
2024-02-15 added schem rev 0.1.3
    [3320-VCF.kicad_sch]
2024-02-16 assigned footprints
    [3320-VCF.kicad_sch, 3320_Control_Board.kicad_sch, 3320_Main_Board.kicad_sch]
2024-02-16 added pcb rev 0.1.0
    [3320-VCF.kicad_pcb, 3320_Main_Board.kicad_sch]
2024-02-16 updated pcb revision 0.1.0
    [3320-VCF.kicad_pcb, 3320_Control_Board.kicad_sch, 3320_Main_Board.kicad_sch]
2024-02-16 updated pcb rev 0.1.0
    [3320-VCF.kicad_pcb, 3320_Main_Board.kicad_sch]
2024-02-16 added pcb rev 0.1.0 separate boards
    [3320_VCF_control_board.kicad_pcb, 3320_VCF_main_board.kicad_pcb]
2024-02-16 generated pcbway gerber zips
    [3320_VCF_control_board.kicad_pcb, 3320_VCF_main_board.kicad_pcb]
2024-02-16 added 3d printed front panel
    [3320_VCF.scad, 3320_VCF.stl, jack_14in.scad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]
2024-04-09 3d printed panel updated
    [3320_VCF.scad, jack_14in.scad, jack_35mm.scad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]
2025-03-11 Add schematic revision 0.1.5
    [3320-VCF.kicad_sch, 3320_Control_Board.kicad_sch, 3320_Main_Board.kicad_sch]
2026-05-14 Fix Build status link path case
2026-05-14 Add photos/ placeholder for assembled-module shots
2026-05-14 Add assembled-module photos and update README hero
2026-05-14 Expand README with features, I/O table, block diagram, calibration, datasheet references
